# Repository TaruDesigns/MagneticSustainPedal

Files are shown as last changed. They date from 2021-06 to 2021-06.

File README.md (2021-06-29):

# MagneticSustainPedal
## Repairs for the F-30 pedal in the VPC1 and other keyboards
The F-30 pedal by Fatar is a 3  pedal unit included in some high end MIDI keyboards, with the Kawai VPC1 being a popular one. This pedal tends to fail after a while so I compiled all the repairs/upgrades onto this repository. The PDFs explains all of these upgrades.

### Magnetic sensor
One of the fixes involves making a custom circuit for one of the pedals. The files for this circuit are to be used with EAGLE, but I've also included the CAM Job so you can order the PCB online.

### Updates

I'm happy with my fix, however, if you try any of the other fixes, feel free to contact me and I will add it to the repo

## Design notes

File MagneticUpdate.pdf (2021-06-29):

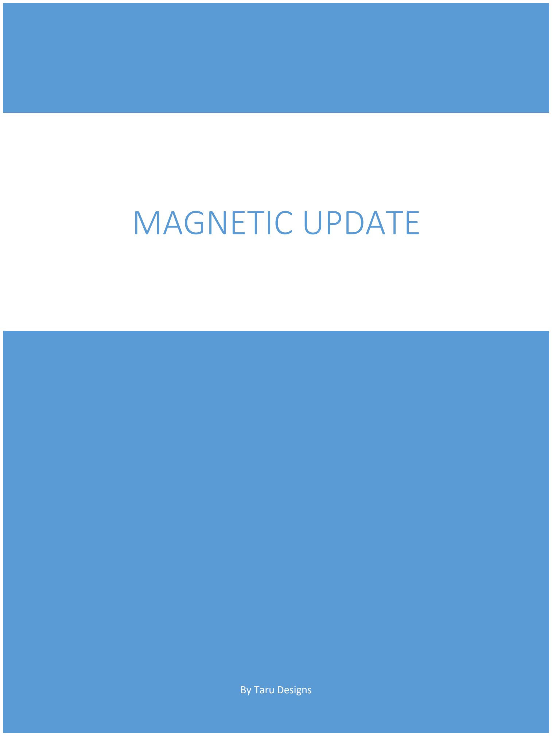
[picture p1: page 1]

By Taru Designs

# MAGNETIC UPDATE

John O’Flaherty goes on to detail his approach in Replacement of the potentiometer in a VPC1 sustain pedal with a non-contact sensor. (https://web.archive.org/web/20181126031410/http:/www.joflaherty.org/HallEffectSustain/VPC1%20pedal%20mod.pdf) I initially followed it and found a few issues:

- I wasn’t able to find that same magnet, but I bought some smaller neodymium magnets that can be stacked for a similar effect.
- When mounted in the way he did, the values output by the pedal weren’t as linear as one would like. This is easily explained by the way the sensor works: It will react to change in magnetic field in the direction of the main face of the IC. Since the pedal moves vertically you’d want to mount the sensor with the main face pointing in the same direction.
- The voltage regulator IC requires some capacitors to work properly. There was one additional issue: With my magnets and the sensor mounted vertically, the change in voltage between the “fully on” and “fully off” position was only ~0.35V. Even after using the calibration tool, the VPC1 would only output 5 or 6 different pedal values.

The Hall effect sensor idles at half the supply voltage, and will either increase or decrease its output voltage depending on the polarity of the magnetic field. For a USB supply, this would mean it idles at 2.5V (without any magnetic field). Since we want to make sure that it detects such magnetic field from the smallest movement, we actually don’t want it to idle at half the supply voltage.

So, to summarize:

- The magnetic sensor works with any magnet, but the voltage swing might be too low for our purpose.
- The VPC1 has a minimum and maximum voltage range that it can assign to MIDI Output 0 and MIDI Output 127 for the sustain pedal: 1.07V for 0 and 2.67V for 127
- Using as much of that range as possible also means having more steps, and overall, a more continuous pedal

The problem then is fairly simple: We have to make it so the idle voltage, as seen by the VPC1 is 1.07, while voltage with the pedal fully depressed is 2.67V (Note: I went for slightly lower range to accommodate for slight variations in components: 1.2V to 2.4V)

The circuit is explained in more detail (including how to calculate the values for each component) in Designing Gain and Offset in Thirty Seconds (https://www.ti.com/lit/an/sloa097/sloa097.pdf?ts=1616137840216) (Positive m and Negative b). From my previous experiments I found that the idle voltage of the sensor could change depending on the mounting position (in other words, the “minimum magnetic field”), but the voltage swing would be the same (which makes sense, since the range of movement in the pedal is always the same). To accommodate for that I replaced R1 and R2 with a multiturn potentiometer so that I can precisely set the offset. In other words:

- R1 and R2 are indirectly compensating the idle voltage
- Rf and Rg amplify the voltage swing. You could also replace one of those with a small potentiometer to adjust the gain if your sensor exhibits a different voltage swing for some reason

I have attached a number of EAGLE files for a generic board. Note that some of the footprints will be unpopulated: Some of the components (USB, Hall sensor) can be easier (and cheaper!) to find in premade breakout boards, so it might make sense to simply buy one of these and plug them in rather than buying them in big quantities just to use one.

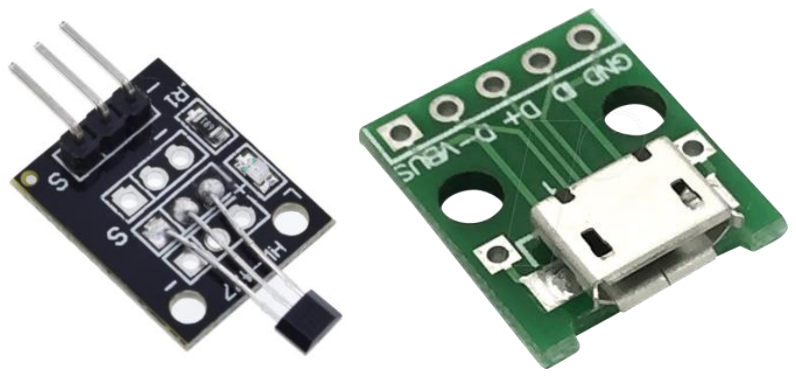
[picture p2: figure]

Since I added another plug, I algo had to (poorly) cut out a hole in the enclosure of the pedal.

Mounting instructions are fairly straightforward:

1. Disconnect the pedal and remove the enclosure
2. Remove the potentiometer and desolder the wires
3. Assemble the board in place and reconnect the two wires
4. Set the magnet into position (I used a piece of steel to offset it from the pedal, but even cardboard would work)
5. Power the board and grab a multimeter: Measure the voltage between the output jack (the tip) and ground.
6. Adjust the potentiometer until this value reads close to 1.2V
7. Depress the pedal and check the voltage when the pedal is all the way down
a. If the voltage decreases, flip the magnet orientation
b. If the voltage doesn’t change or only changes a few millivolts, the magnet is not strong enough/it’s too far. Use a more powerful magnet or move it closer to the sensor.
8. Once you get the desired range, assemble the pedal again and connect it to the keyboard.

Parts List for the board:

Designation | Value | Description | Note
R1 | 200K | Multiturn trimmer
R2 | 220K | 0805 Resistor
R3 | 470K | 0805 Resistor
IC1 | LM358 | Low Voltage Dual Opamp
X1 | USB Type B
| Female | PCB Mount right angle
| | connector | Alternatives: External power on JP2
IC2 | A1321 | Hall Sensor | Alternatives: SS49E, A1301
JP1 | 3-pin header | 2.54mm pitch, male | Optional: Only for external board replacing IC2
JP2 | 2-pin header | 2.54mm pitch, male | Alternative: USB power
JP3 | 2-pin header | 2.54mm pitch, male | Optional: Solder wires directly to board.

As for magnets, I personally bought these on amazon:

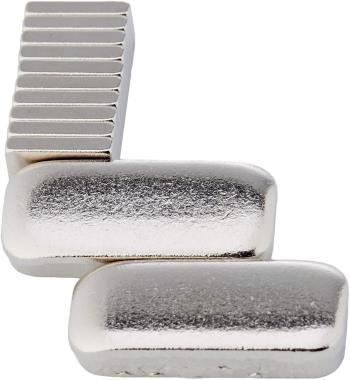
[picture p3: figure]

Here are some pics of the interior of the pedal with this upgrade. Since this was done very much in a hurry, it doesn’t look nearly as nice as it should.

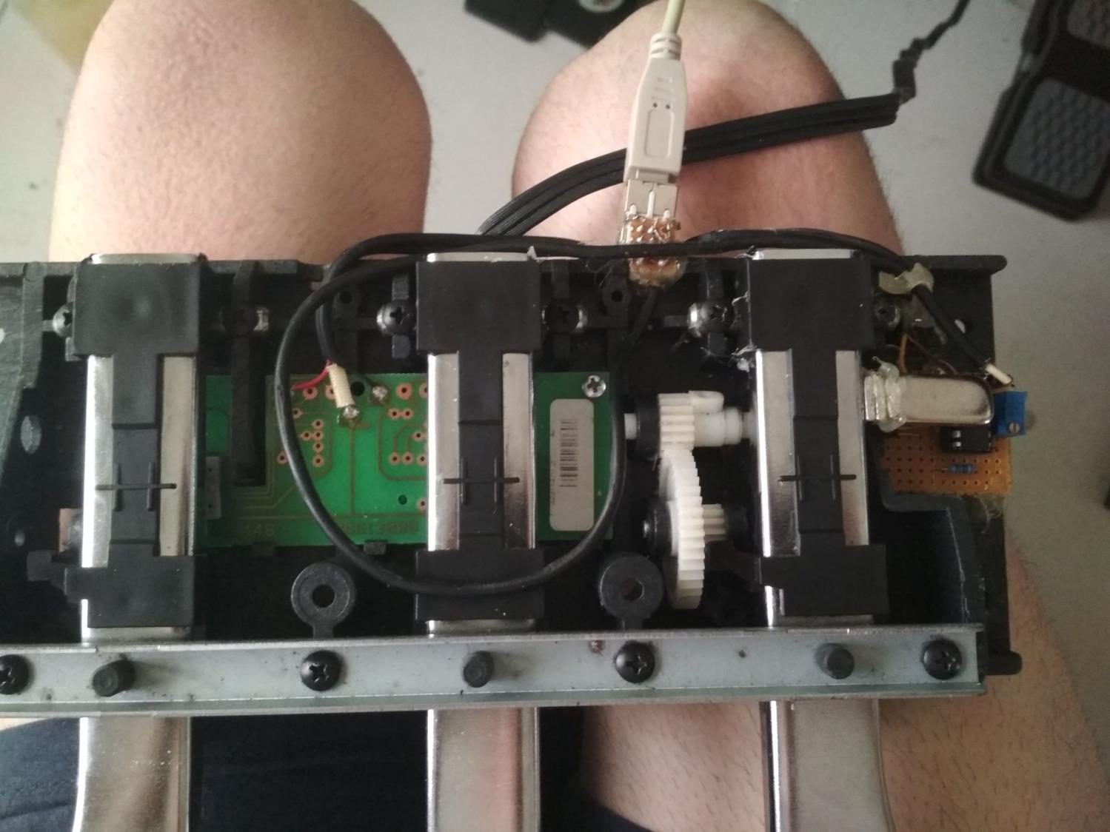
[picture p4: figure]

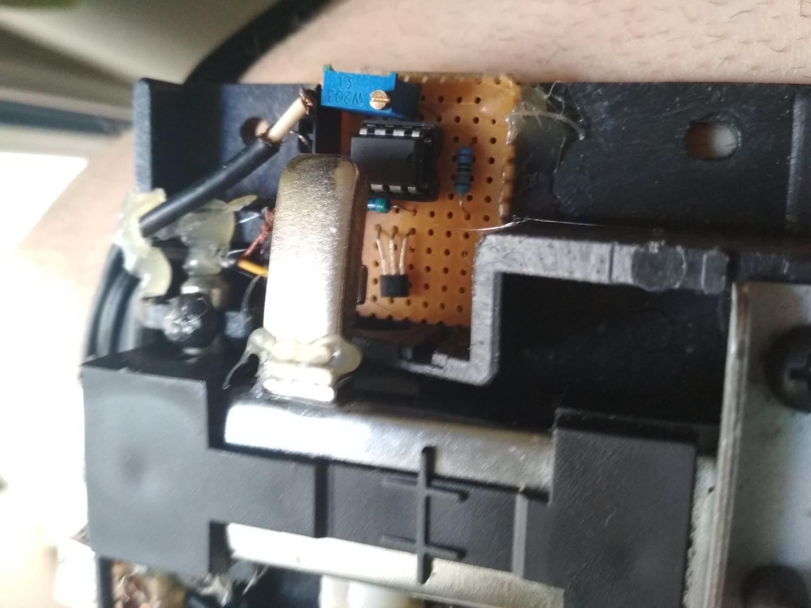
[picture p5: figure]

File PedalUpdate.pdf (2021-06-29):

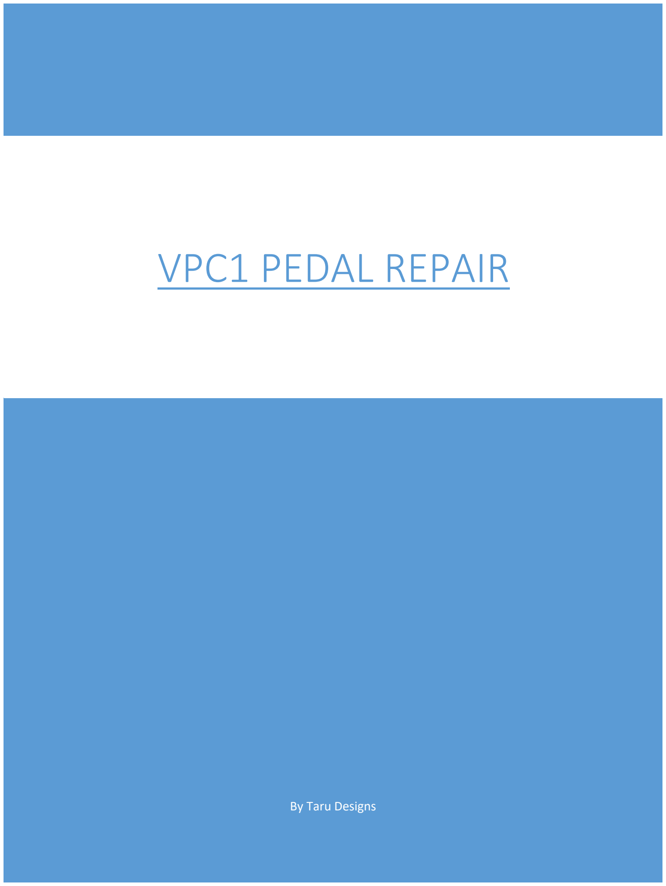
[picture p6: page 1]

By Taru Designs

# VPC1 PEDAL REPAIR

What’s wrong with the pedal?: The F-30 triple pedal included in the VPC1 is not the most reliable piece of hardware. The sustain pedal tends to fail over time, and even though there’s a calibration tool available, it won’t completely fix it. The sustain pedal on the VPC-1 is based on a standard, carbon track potentiometer. This potentiometer is actuated by means of a simple mechanical rack and pinion gearing system. When the pedal is depressed, the linear motion is converted into rotational motion, which then turns the potentiometer shaft directly.

Why it breaks: Resistive track potentiometers such as these are not well suited to constant operation and even those that are specifically rated for high number of operations would eventually fail (incidentally, this is also why the joysticks in some gamepads drift after some use, the Joycons in the Nintendo Switch are especially prone to this for example). Initially, some dust might settle inside the potentiometer (since it’s not fully sealed). This is easy to fix with some contact cleaner. However, the wiper inside the potentiometer scratches the carbon track so you end up with unreliable readings on its travel.

This project is heavily based off John O’Flaherty’s

This project is going to list a number of alternatives and repairs:

1. Using a cheap, “ON/OFF” sustain pedal, connected to the same jack: You would lose half pedaling as well as the middle pedal, but it’s better than having the pedal randomly spit values.
2. Using a not-so-cheap half pedal such as the Roland DP-10: You would lose the middle pedal but at least you could have half pedal capabilities.
3. Replacing the potentiometer every few months: This would work, but it is more of a temporary fix. I have done this without much trouble, the potentiometer is not the easiest to find but also not particularly hard. You would need a 20K linear potentiometer with a short, “D” shaft such as this one:

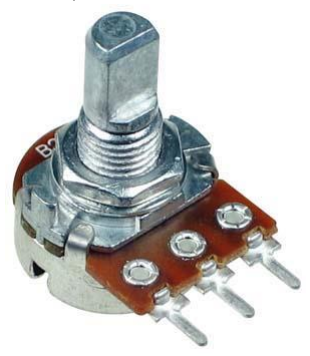
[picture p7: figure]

You might be able to find this with short, single pin leads such as the one in the picture, or longer, ring leads. Both of those can be used, as you would solder the wires directly to either of them. The important dimensions are
- 6 mm diameter Shaft
- 16mm diameter Base
4. Use an external MIDI pedal: You could use any pedal that outputs continuous CC64 values. Ideally, it would have a standard MIDI connector that would plug straight into the VPC1, but one that simply connects to your computer would work as well. I don’t know of any off the shelf pedals that would work for this however.

- You could also mod your existing F-30 pedal to act as a standalone MIDI pedal. Costis has a fantastic guide on doing this with magnetic sensors. (https://www.hackster.io/costis/usb-standalone-triple-piano-pedal-kawai-f-30-hack-e626b6) I recommend this approach if you don’t want to solder any wires
5. Replace the potentiometer with a rotary encoder: Optical rotary encoders are significantly more reliable than resistive tracks on potentiometers, but they require additional circuitry to convert those steps to the proper voltage: A small microcontroller such as an ATTiny and a digital potentiometer like the MCP4551 should work. Since most rotary encoders come in smaller sizes than the potentiometer, you would still need to match the size and mounting position for the shaft, and/or 3D print a custom mount and adapter for the shaft.
- I haven’t tried it, but the Kawai F-10H allegedly uses “optical sensing”. By default, it is not compatible with the VPC1 as the VPC1 does not really provide power through its pedal inputs, but it should be possible to simply add external power supply and reroute the voltage output to the right spot in the original VPC1 pedal’s board.
6. Remove the potentiometer altogether and go for a non contact, magnetic sensor: This requires both electronics (including an external power supply) and, well, magnets. In some ways, it is less forgiving than the encoder, but it is just as reliable and much more forgiving to mount. For more details on this option, check MagneticUpdate

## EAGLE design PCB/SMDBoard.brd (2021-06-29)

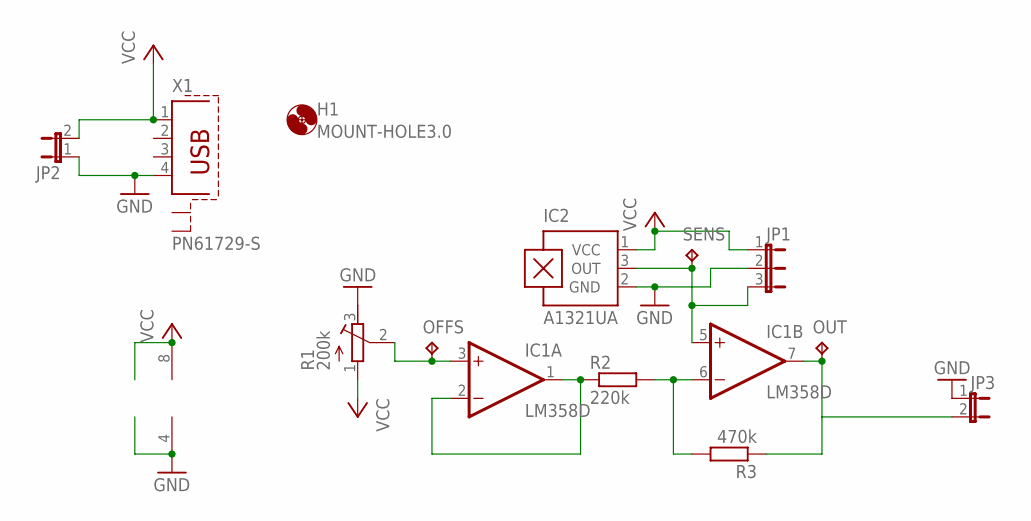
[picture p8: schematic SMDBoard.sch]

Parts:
H1: MOUNT-HOLE3.0; 3,0
IC1: LM358D; SO08
IC2: A1321UA; SIP3-UA
JP1: JP2E; JP2
JP2, JP3: JP1E; JP1
OFFS: TPB1,27; B1,27
OUT: TPB1,27; B1,27
R1: 200k; RTRIM3296W
R2: 220k; R0805
R3: 470k; R0805
SENS: TPB1,27; B1,27
X1: PN61729-S

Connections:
GND: IC1.4 (V-), IC2.2 (GND), JP1.2, JP2.1, JP3.1, R1.3 (E), X1.4
unnamed: IC1.1 (OUT), IC1.2 (-IN), R2.1
unnamed: IC1.6 (-IN), R2.2, R3.2
unnamed: IC1.7 (OUT), JP3.2, OUT.TP, R3.1
unnamed: IC1.5 (+IN), IC2.3 (OUT), JP1.3, SENS.TP
OFFS: IC1.3 (+IN), OFFS.TP, R1.2 (S)
VCC: IC1.8 (V+), IC2.1 (VCC), JP1.1, JP2.2, R1.1 (A), X1.1

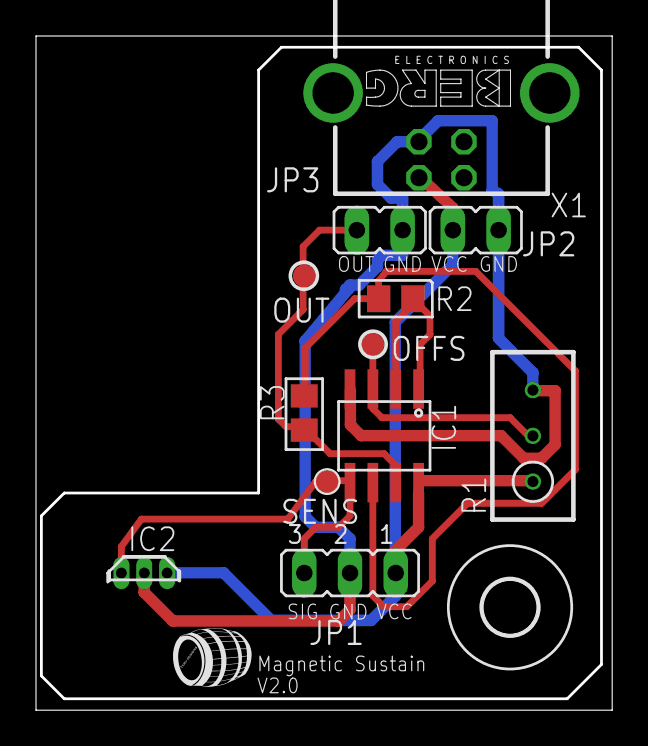
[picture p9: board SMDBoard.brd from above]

Board: 2 copper layers, 32.0 x 37.5 mm, 13 parts (0 on the bottom side), 7 nets.
